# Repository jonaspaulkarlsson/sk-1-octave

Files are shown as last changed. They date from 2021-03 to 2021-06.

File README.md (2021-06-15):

# sk-1-octave
## Octave switch for the Casio SK-1 keyboard

## Background
The SK-1 is a great keyboard, but it's range is limited due to the short 2.5 octave keyboard.

Looking at the schematic in the service manual (http://www.burnkit2600.com/manuals/CASIO_SK-1_SRVC.pdf), the clock for the microprocessor is generated by a simple LC oscillator, like what is presented here: http://www.learningaboutelectronics.com/Articles/Colpitts-oscillator-calculator.php.

The tuning of the instrument is controlled by a variable capacitor, which controls the frequency of the LC clock oscillator. The idea is to replace the inverter in the original oscillator with a CMOS inverter IC, add a clock divider to drop the frequency by four (down two octaves) and a multiplexer to select either the original or the divided frequency.

PCB area around the micro processor and LC oscillator circuit:
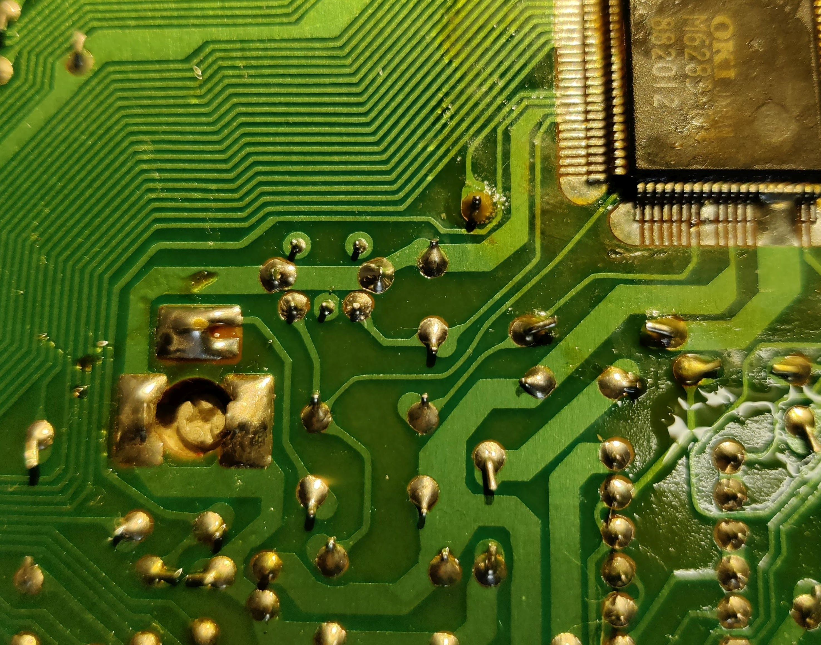
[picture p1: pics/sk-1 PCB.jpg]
SK-1 PCB


Original oscillator input signal:
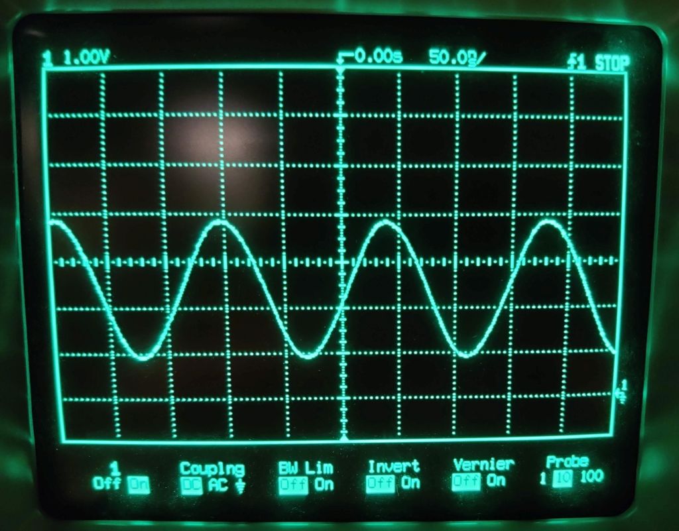
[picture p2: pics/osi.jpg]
OSI pin signal


Original oscillator output signal:
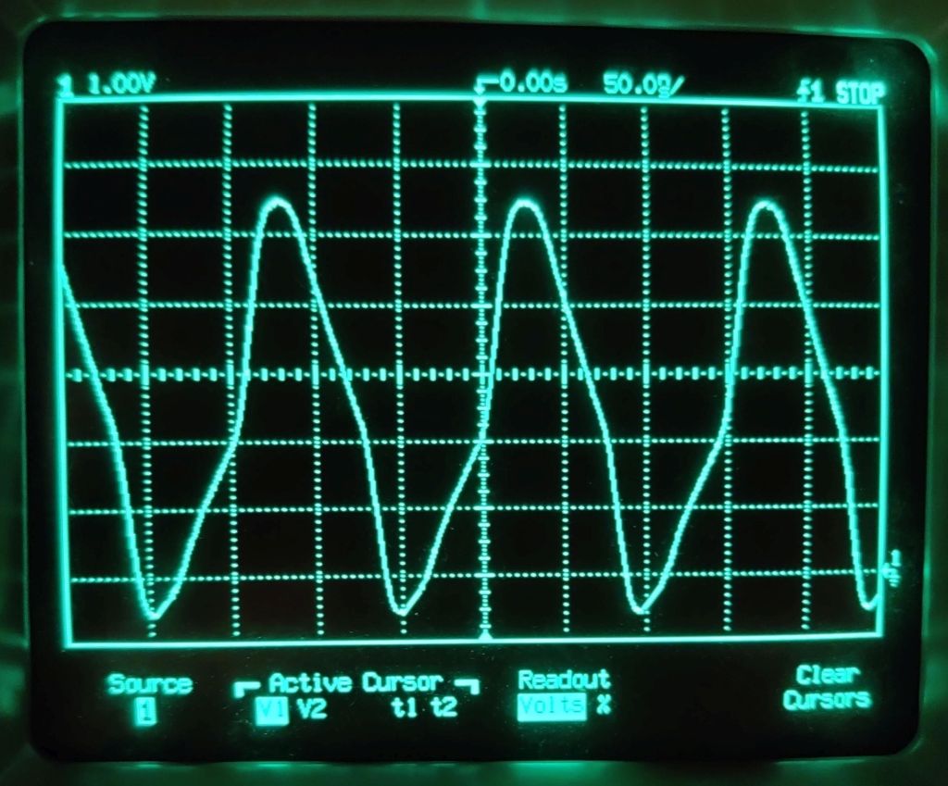
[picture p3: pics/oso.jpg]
OSO pin signal


## Circuit design
The schematic and PCB was designed in KiCad.

The schematic below shows the circuit:
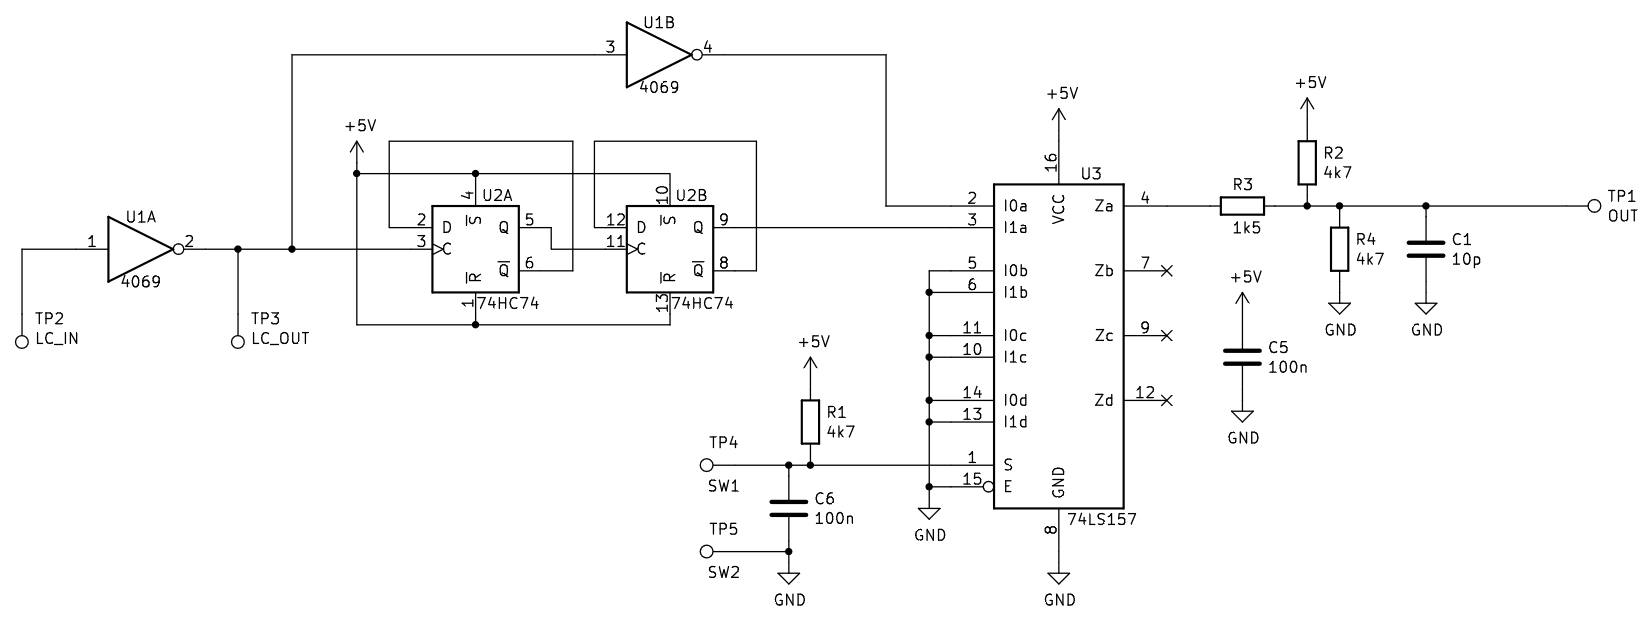
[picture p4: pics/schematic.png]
Octave switch schematic


The oscillator core consists of the existing inductor and capacitors from the original circuit, but now connected to one part of U1, a 4069 hex CMOS inverter. The signal from the oscillator is divided by four by two stages from U2, a dual D flip-flop. Lastly, one of the original or divided down signals are selected by one channel of U3, a quad mux. The select input of the mux is connected to a switch that selects either the original frequency when the switch is closed, or the divided down frequency when the switch is open.

The R2, R3, R4 and C1 network scales the output to roughly the same voltage range as the original clock signal. This is probably not necessary but the circuit was included just to be safe. In the end, C1 was excluded.

The PCB is shown in the picture below:
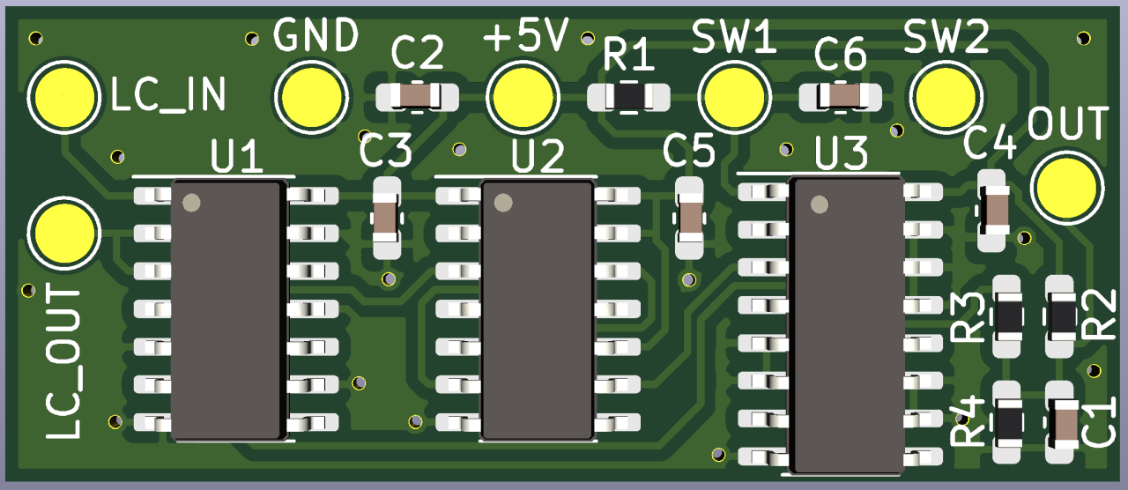
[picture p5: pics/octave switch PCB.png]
Octave switch PCB


All connections are made to test points around the edges for easy soldering.

## Installation
1. Open upp the case and place both halves upside down, exposing the main PCB.
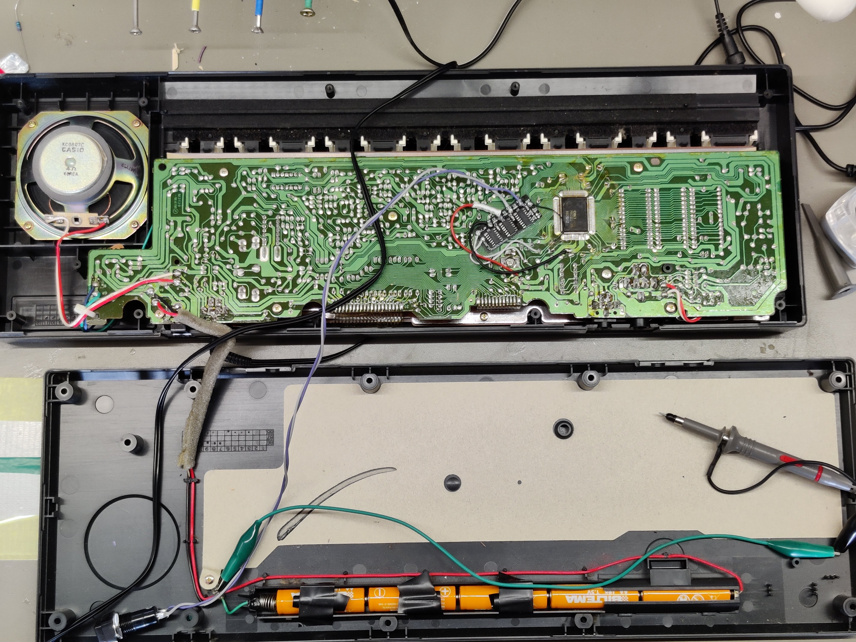
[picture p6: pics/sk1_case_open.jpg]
SK-1, case open
2. Mount the octave switch PCB with double sided tape, hot glue or whatever you have at hand in the position shown in the picture 
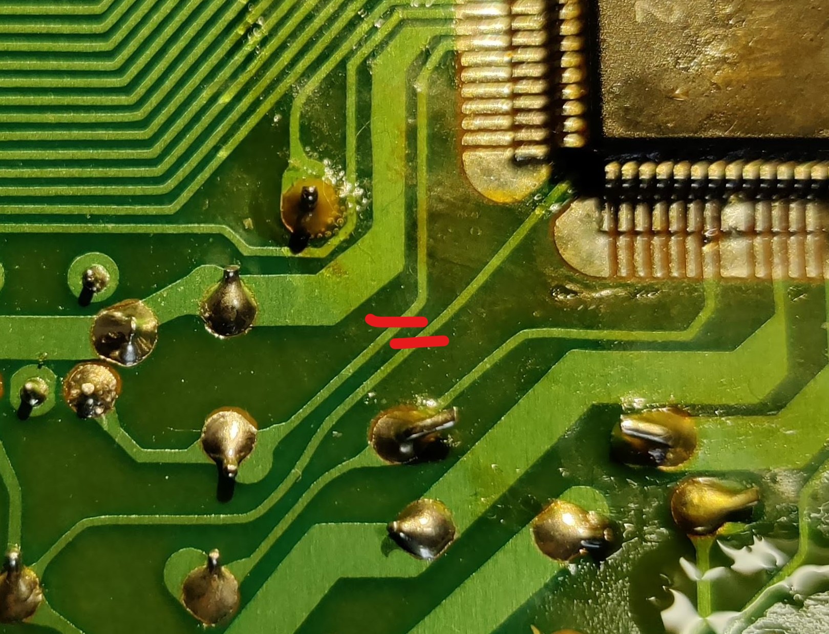
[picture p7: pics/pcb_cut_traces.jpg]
Cut traces
3. Cut the traces going to the processor where indicated by the red lines in the picture, and scrape off the solder resist on the one going in under the corner of the IC: 
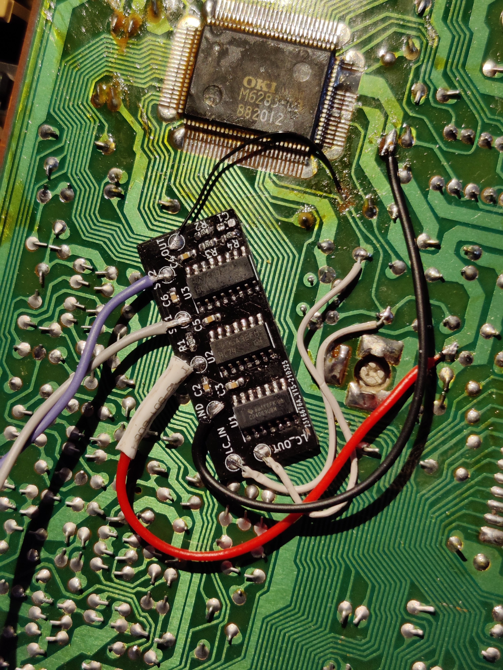
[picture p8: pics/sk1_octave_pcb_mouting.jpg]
Connecting PCB
4. Solder wires to the octave switch PCB from the solder joints on the SK-1 PCB as shown in the picture. Solder in the OUT signal with as thin a wire as possible to minimize stress on the cut wire. Take care to leave the area close to the tuning inductor free from wires. 
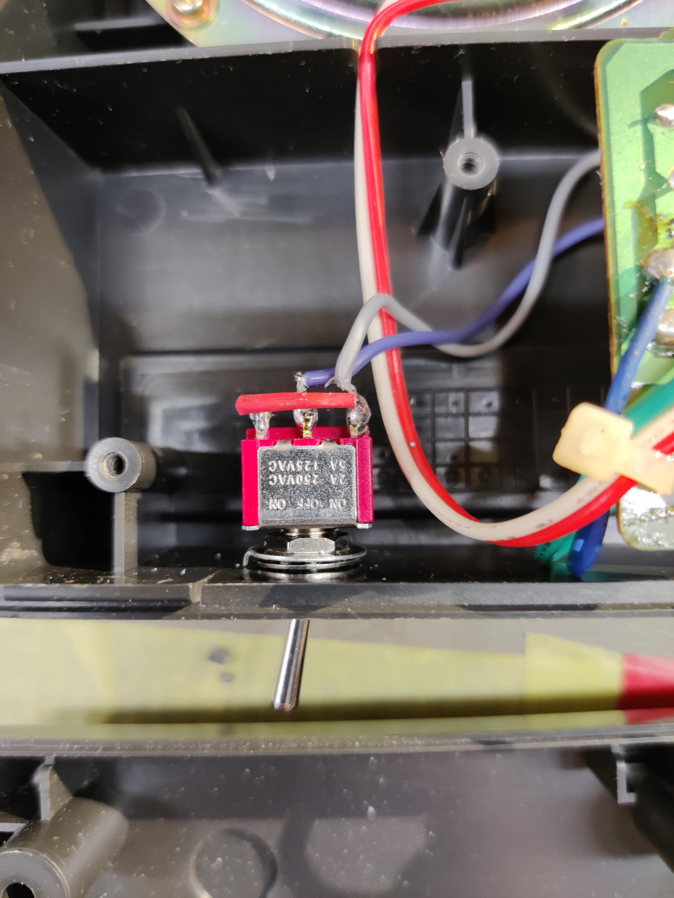
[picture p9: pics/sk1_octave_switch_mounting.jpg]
Mounting octave switch
5. Mount a toggle swithch to some convenient place in the case, probaly the empty space next to the speaker is most convenient. Connect the switch with long twisted wires to the SW1 and SW2 pads. 
6. Put your SK-1 back together and enjoy your extended note range!

It should be noted that the SK-1 uses a weird form of negative logic, so what is connected to GND the octave switch PCB is actually the negative supply rail, and what is connected to +5V is ground. What matters in the end is that both PCBs sees signals that are in the correct voltage ranges for their respective supplies.

## Results
Audio demos at [Soundcloud](https://soundcloud.com/exterm/sk-1-octave)

The circuit works well and unlocks some of the potential of this instrument. I really like the cruncy atmospheric sound of the lower octaves.

However there are some side effects (features?) due to the nature of this hack. Since the clock speed for the whole system is slowed down, _everything_ slows down. Rythms (nice and crunchy, but slow), portamento, vibrato, envelopes etc. It doesn't bother me too much, but it should be noted that the integration is not seamless.

## Retrospective
1. I thought I ordered 1mm thick PCBs, but apparently it was the standard 1.6mm. I wanted to keep as much clearance to the case as possible, not knowing exactly how much room there was, but 1.6mm worked out fine.
2. The black solder resist fom JLCPCB was quite fragile and chipped away in one place. I will go for the standard green in the future.
3. It would have been cool to design the PCB around the solder in poisitions on the SK-1 PCB so that it could be attached directly with castellated edges. It would have been a fun exercise. Maybe for another project.
4. Yes I know the soldering looks awful, I should probably redo it, but... meh.
5. The SK-1 PCB is covered in sticky flux. I did clean it up around the area where I attached the octave switch PCB, but yeah, I know it looks nasty.

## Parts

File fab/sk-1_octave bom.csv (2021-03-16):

Ref | Qnty | Value | Footprint | Description
C1, | 1 | 10p | 0603 | Ceramic capacitor
C2, C3, C4, C5, C6, | 5 | 100n | 0603 | Ceramic capacitor
R1, R2, R4, | 3 | 4k7 | 0603 | Resistor
R3, | 1 | 1k5 | 0603 | Resistor
U1, | 1 | CD4069UBM | SOIC-14 | Hex inverter
U2, | 1 | SN74HC74DR | SOIC-14 | Dual D Flip-flop, Set & Reset
U3, | 1 | SN74HC157DR | SOIC-16 | Quad 2 to 1 line Multiplexer

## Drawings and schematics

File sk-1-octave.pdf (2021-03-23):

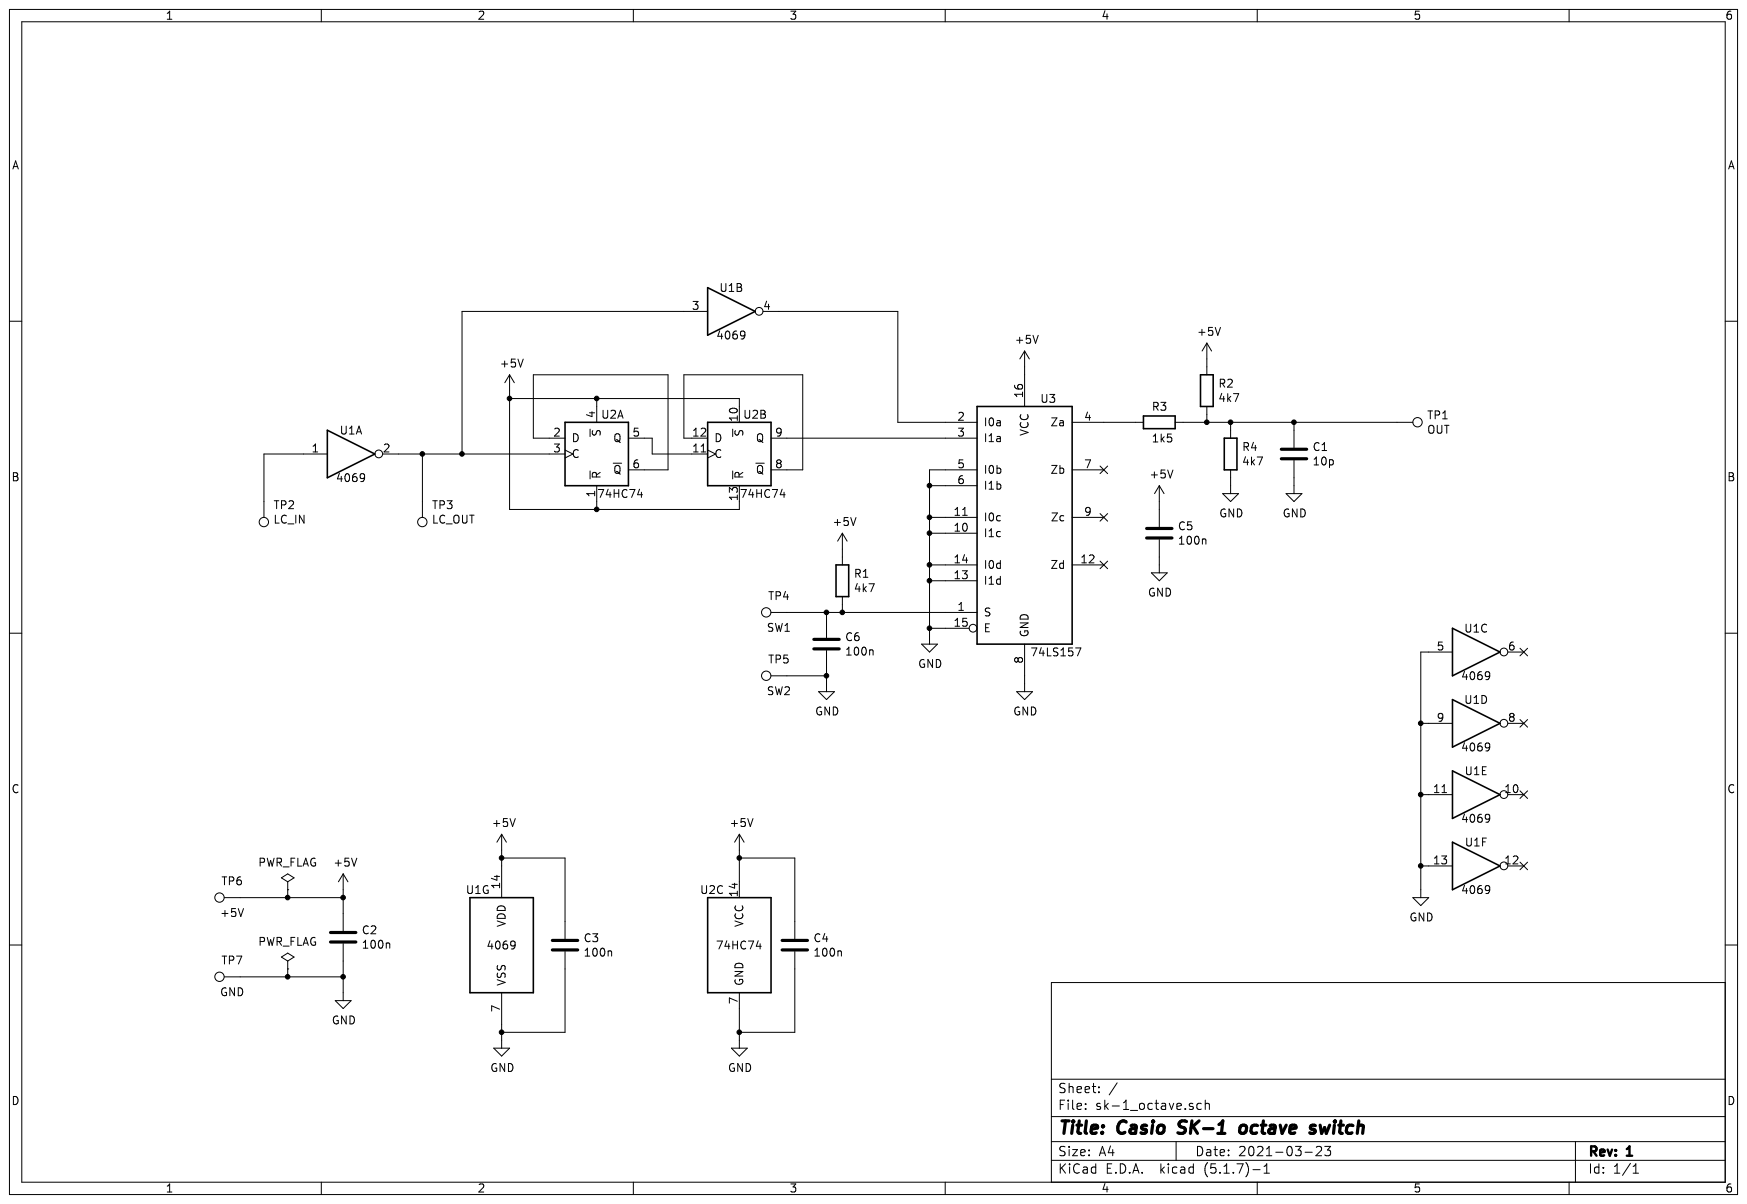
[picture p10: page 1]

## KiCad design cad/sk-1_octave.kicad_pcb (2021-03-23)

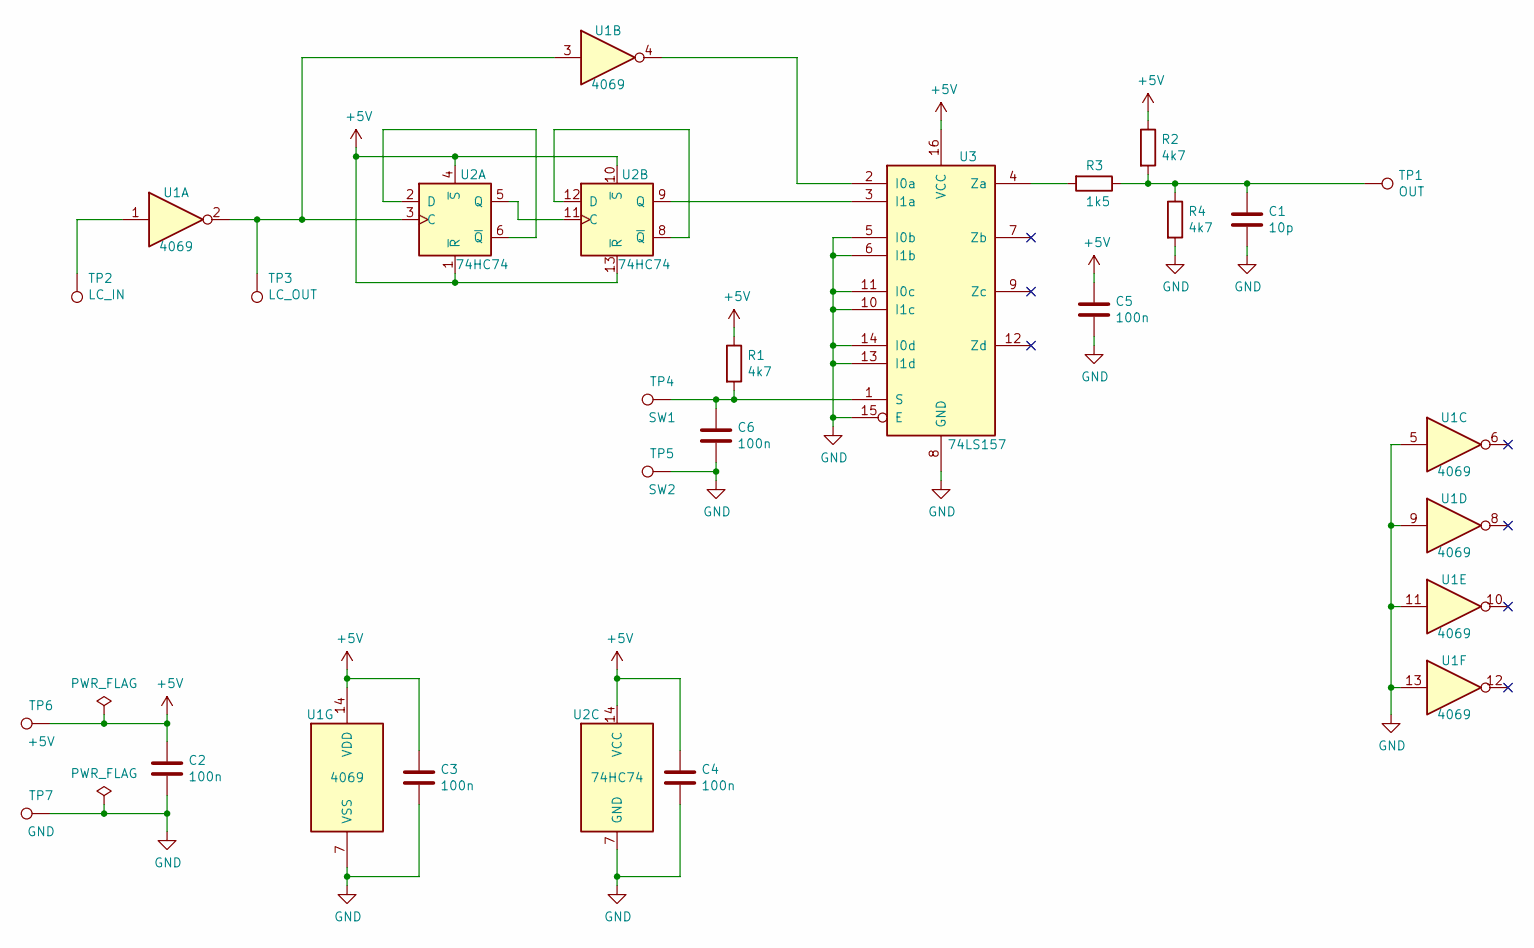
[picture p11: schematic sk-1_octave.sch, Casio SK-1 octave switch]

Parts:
C1: 10p; C_0603_1608Metric_Pad1.08x0.95mm_HandSolder
C2, C3, C4, C5, C6: 100n; C_0603_1608Metric_Pad1.08x0.95mm_HandSolder
R1, R2, R4: 4k7; R_0603_1608Metric_Pad0.98x0.95mm_HandSolder
R3: 1k5; R_0603_1608Metric_Pad0.98x0.95mm_HandSolder
TP1: OUT; TestPoint_Pad_D2.0mm
TP2: LC_IN; TestPoint_Pad_D2.0mm
TP3: LC_OUT; TestPoint_Pad_D2.0mm
TP4: SW1; TestPoint_Pad_D2.0mm
TP5: SW2; TestPoint_Pad_D2.0mm
TP6: +5V; TestPoint_Pad_D2.0mm
TP7: GND; TestPoint_Pad_D2.0mm
U1: 4069; SO-14_3.9x8.65mm_P1.27mm
U2: 74HC74; SO-14_3.9x8.65mm_P1.27mm
U3: 74LS157; SOIC-16_3.9x9.9mm_P1.27mm

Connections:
+5V: C2.1, C3.1, C4.1, C5.1, R1.1, R2.1, TP6.1, U1.14 (VDD), U2.1 (~R), U2.4 (~S), U2.10 (~S), U2.13 (~R), U2.14 (VCC), U3.16 (VCC)
GND: C1.2, C2.2, C3.2, C4.2, C5.2, C6.2, R4.2, TP5.1, TP7.1, U1.5, U1.7 (VSS), U1.9, U1.11, U1.13, U2.7 (GND), U3.5 (I0b), U3.6 (I1b), U3.8 (GND), U3.10 (I1c), U3.11 (I0c), U3.13 (I1d), U3.14 (I0d), U3.15 (E)
unnamed: C1.1, R2.2, R3.1, R4.1, TP1.1
unnamed: C6.1, R1.2, TP4.1, U3.1 (S)
unnamed: R3.2, U3.4 (Za)
unnamed: TP2.1, U1.1
unnamed: TP3.1, U1.2, U1.3, U2.3 (C)
unnamed: U1.4, U3.2 (I0a)
unnamed: U2.2 (D), U2.6 (~Q)
unnamed: U2.9 (Q), U3.3 (I1a)
unnamed: U2.5 (Q), U2.11 (C)
unnamed: U2.8 (~Q), U2.12 (D)

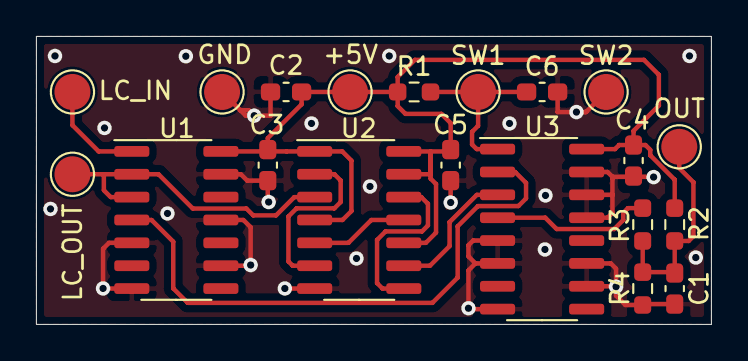
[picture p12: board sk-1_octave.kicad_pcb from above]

Board: 2 copper layers, 37.5 x 16.0 mm, 20 parts (0 on the bottom side), 12 nets.

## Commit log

2021-03-11 PCB project files
    [sk-1_octave.kicad_pcb, sk-1_octave.sch]
2021-03-14 Moved CAD files to separate folder
    [sk-1_octave.kicad_pcb, sk-1_octave.sch]
2021-03-14 Added output signal conditioning.
    [sk-1_octave.kicad_pcb, sk-1_octave.sch]
2021-03-16 Minor cleanup of PCB. Generated gerbers and drill files. Created BOM.
    [sk-1_octave bom.csv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]
2021-03-23 Minor tweaks to layout. Added documentation.
    [sk-1_octave-B_Cu.gbr, sk-1_octave-B_Mask.gbr, sk-1_octave-Edge_Cuts.gbr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]
2021-05-01 74LSS157 -> 74HCS157. Removed backup files from versioning.
    [sk-1_octave.sch]
2021-06-13 74HCS157 -> 74HC157
    [sk-1_octave.sch]
